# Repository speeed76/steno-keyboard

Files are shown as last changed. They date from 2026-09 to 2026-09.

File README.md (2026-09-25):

# Steno/QWERTY dual-mode keyboard

A 42-key keyboard (3×12 + 6 thumb keys) that works as a normal QWERTY keyboard
or as a steno machine that translates chords **on the keyboard itself**, so the
computer needs no Plover install.

## Status

| Part | State |
|---|---|
| PCB (`hardware/`) | placed and netlisted, **not routed yet**. Ergogen generates `hardware/ergogen/output/pcbs/steno_qwerty.kicad_pcb`; traces still need routing in KiCad |
| Firmware (`firmware/`) | **draft, never run on hardware.** The steno engine works on a desktop against Plover's real dictionary; USB and matrix code is untested |
| Dictionary compiler (`tools/build_dictionary.py`) | works: Plover `main.json` → 2.8 MB binary file |

## Hardware constraint found so far

Plover's default dictionary is still ~2.6 MB after compiling to a compact
binary format. A standard Raspberry Pi Pico (2 MB flash, ~1 MB free under
CircuitPython) **cannot hold it**. The PCB uses the standard Pico footprint,
but fit a module with ≥4 MB of flash (Raspberry Pi Pico 2) or, better, 16 MB.

## PCB

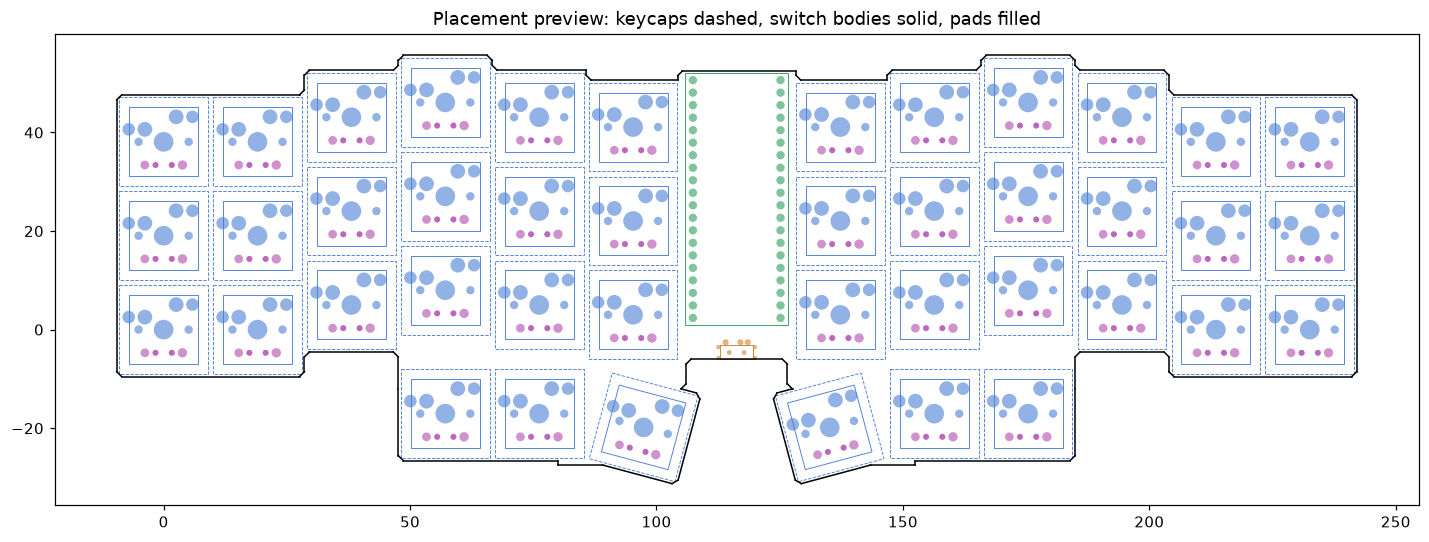
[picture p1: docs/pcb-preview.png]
placement preview


- 42 MX switches with Kailh hotswap sockets, one diode per key (SOD-123 or THT 1N4148)
- Raspberry Pi Pico-footprint module, soldered through-hole, USB at the top edge
- MSK-12C02 slide switch at the bottom notch: GP22 to GND, closed = steno
- Matrix: rows GP6–GP9, columns GP0–GP5 (left) and GP21–GP16 (right), matching `firmware/stenokb/config.py`
- Board is ~250 × 88 mm: over JLCPCB's 100 × 100 mm budget tier, so expect ~$25–40 for 5 bare boards

Regenerate and check it:

```sh
npx ergogen@4.2.1 hardware/ergogen -o hardware/ergogen/output --clean
python3 hardware/tools/check_pcb.py hardware/ergogen/output/pcbs/steno_qwerty.kicad_pcb --png docs/pcb-preview.png
```

`check_pcb.py` is a quick placement check (single board outline, pads inside
it, no colliding switches/keycaps/Pico/switch), not a substitute for KiCad's DRC.

### Remaining steps before ordering

1. Open the `.kicad_pcb` in KiCad 8/9 and route it: by hand, with Freerouting
   (export Specctra DSN, route, import SES), or with Quilter.
2. Add GND fill zones on both layers and run DRC.
3. Plot Gerbers and drill files and upload them to JLCPCB/PCBWay.

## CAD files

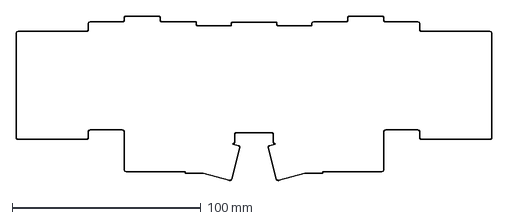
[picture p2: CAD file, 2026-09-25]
hardware/ergogen/output/outlines/board.dxf
251.6 x 87.0 mm

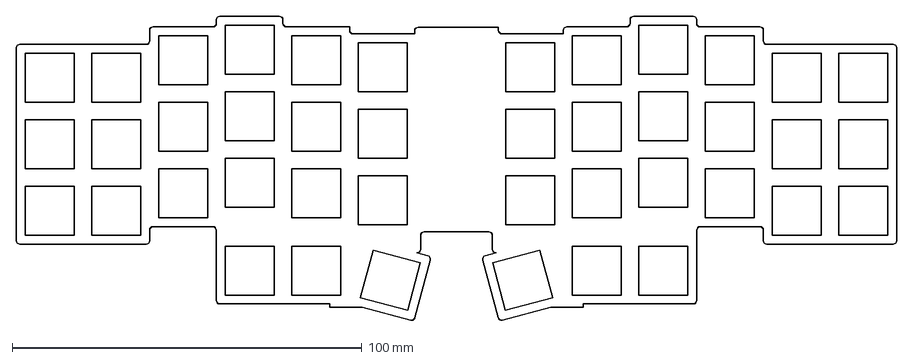
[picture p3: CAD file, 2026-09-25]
hardware/ergogen/output/outlines/preview.dxf
251.6 x 87.0 mm

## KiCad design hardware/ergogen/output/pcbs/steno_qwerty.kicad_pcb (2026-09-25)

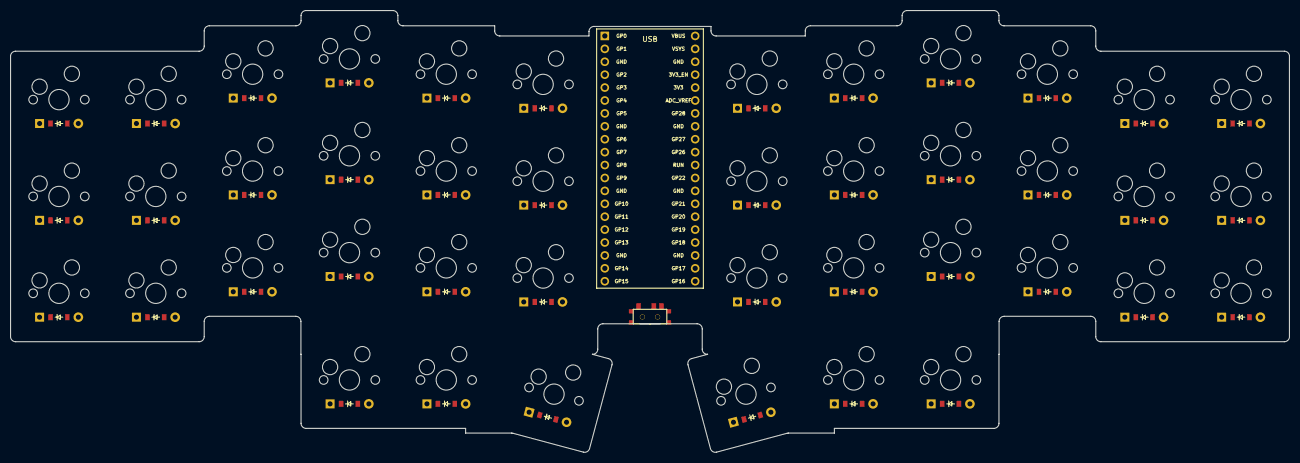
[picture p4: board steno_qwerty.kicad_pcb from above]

Board: 2 copper layers, 251.6 x 86.9 mm, 86 parts (0 on the bottom side), 60 nets, no tracks yet.

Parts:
D1, D2, D3, D4, D5, D6, D7, D8, D9, D10, D11, D12, D13, D14, D15, D16, D17, D18, D19, D20, D21, D22, D23, D24, D25, D26, D27, D28, D29, D30, D31, D32, D33, D34, D35, D36, D37, D38, D39, D40, D41, D42: ComboDiode
MCU1: RPi Pico; RPi_Pico
S1, S2, S3, S4, S5, S6, S7, S8, S9, S10, S11, S12, S13, S14, S15, S16, S17, S18, S19, S20, S21, S22, S23, S24, S25, S26, S27, S28, S29, S30, S31, S32, S33, S34, S35, S36, S37, S38, S39, S40, S41, S42: MX
T1: SPDT_C128955

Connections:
GND: MCU1.3, MCU1.8, MCU1.13, MCU1.18, MCU1.23, MCU1.28, MCU1.33, MCU1.38, T1.2
GP0: MCU1.1, S1.1, S2.1, S3.1
GP1: MCU1.2, S4.1, S5.1, S6.1
GP2: MCU1.4, S7.1, S8.1, S9.1
GP3: MCU1.5, S10.1, S11.1, S12.1, S19.1
GP4: MCU1.6, S13.1, S14.1, S15.1, S20.1
GP5: MCU1.7, S16.1, S17.1, S18.1, S21.1
GP6: D3.1, D6.1, D9.1, D12.1, D15.1, D18.1, D24.1, D27.1, D30.1, D33.1, D36.1, D39.1, MCU1.9
GP7: D2.1, D5.1, D8.1, D11.1, D14.1, D17.1, D23.1, D26.1, D29.1, D32.1, D35.1, D38.1, MCU1.10
GP8: D1.1, D4.1, D7.1, D10.1, D13.1, D16.1, D22.1, D25.1, D28.1, D31.1, D34.1, D37.1, MCU1.11
GP9: D19.1, D20.1, D21.1, D40.1, D41.1, D42.1, MCU1.12
GP16: MCU1.21, S22.1, S23.1, S24.1
GP17: MCU1.22, S25.1, S26.1, S27.1
GP18: MCU1.24, S28.1, S29.1, S30.1
GP19: MCU1.25, S31.1, S32.1, S33.1, S40.1
GP20: MCU1.26, S34.1, S35.1, S36.1, S41.1
GP21: MCU1.27, S37.1, S38.1, S39.1, S42.1
GP22: MCU1.29, T1.1
far_cluster: D21.2, S21.2
home_cluster: D20.2, S20.2
index_bottom: D13.2, S13.2
index_home: D14.2, S14.2
index_top: D15.2, S15.2
inner_bottom: D16.2, S16.2
inner_home: D17.2, S17.2
inner_top: D18.2, S18.2
middle_bottom: D10.2, S10.2
middle_home: D11.2, S11.2
middle_top: D12.2, S12.2
mirror_far_cluster: D42.2, S42.2
mirror_home_cluster: D41.2, S41.2
mirror_index_bottom: D34.2, S34.2
mirror_index_home: D35.2, S35.2
mirror_index_top: D36.2, S36.2
mirror_inner_bottom: D37.2, S37.2
mirror_inner_home: D38.2, S38.2
mirror_inner_top: D39.2, S39.2
mirror_middle_bottom: D31.2, S31.2
mirror_middle_home: D32.2, S32.2
mirror_middle_top: D33.2, S33.2
mirror_near_cluster: D40.2, S40.2
mirror_outer_bottom: D22.2, S22.2
mirror_outer_home: D23.2, S23.2
mirror_outer_top: D24.2, S24.2
mirror_pinky_bottom: D25.2, S25.2
mirror_pinky_home: D26.2, S26.2
mirror_pinky_top: D27.2, S27.2
mirror_ring_bottom: D28.2, S28.2
mirror_ring_home: D29.2, S29.2
mirror_ring_top: D30.2, S30.2
near_cluster: D19.2, S19.2
outer_bottom: D1.2, S1.2
outer_home: D2.2, S2.2
outer_top: D3.2, S3.2
pinky_bottom: D4.2, S4.2
pinky_home: D5.2, S5.2
pinky_top: D6.2, S6.2
ring_bottom: D7.2, S7.2
ring_home: D8.2, S8.2
ring_top: D9.2, S9.2

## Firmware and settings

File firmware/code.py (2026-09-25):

"""Dual-mode steno/QWERTY keyboard firmware (CircuitPython, RP2040/RP2350).

QWERTY mode: a layered 42-key keyboard.
Steno mode: chords are translated on the keyboard itself using the dictionaries
in /dictionaries and typed out as ordinary keystrokes, so the computer needs no
steno software.
"""

import time

import board
import digitalio
import keypad
import usb_hid
from adafruit_hid.keyboard import Keyboard
from adafruit_hid.keyboard_layout_us import KeyboardLayoutUS

from stenokb import config, layout
from stenokb.chord import ChordCollector
from stenokb.device import HidKeys, StenoOutput, load_dictionaries
from stenokb.qwerty import Qwerty
from stenokb.translator import Translator


def pin(name):
    return getattr(board, name)


keyboard = Keyboard(usb_hid.devices)
steno_out = StenoOutput(keyboard, KeyboardLayoutUS(keyboard))

matrix = keypad.KeyMatrix(
    row_pins=[pin(p) for p in config.ROW_PINS],
    column_pins=[pin(p) for p in config.COL_PINS],
    columns_to_anodes=config.COLUMNS_TO_ANODES,
    interval=config.DEBOUNCE_SECONDS,
)

mode_switch = None
if config.MODE_SWITCH_PIN:
    mode_switch = digitalio.DigitalInOut(pin(config.MODE_SWITCH_PIN))
    mode_switch.switch_to_input(pull=digitalio.Pull.UP)

led = None
if config.LED_PIN and hasattr(board, config.LED_PIN):
    led = digitalio.DigitalInOut(pin(config.LED_PIN))
    led.switch_to_output()

translator = Translator(load_dictionaries(config.DICTIONARIES), steno_out)
chords = ChordCollector(layout.STENO)
state = {"mode": None}


def set_mode(mode):
    if mode == state["mode"]:
        return
    qwerty.release_all()
    keyboard.release_all()
    chords.reset()
    translator.reset()
    state["mode"] = mode
    if led:
        led.value = mode == "steno"
    print("mode:", mode)


qwerty = Qwerty(layout.LAYERS, HidKeys(keyboard), on_steno=lambda: set_mode("steno"))


def switch_mode():
    return "steno" if not mode_switch.value else "qwerty"


last_switch = switch_mode() if mode_switch else None
set_mode(last_switch or config.DEFAULT_MODE)

event = keypad.Event()
while True:
    if mode_switch:
        position = switch_mode()
        if position != last_switch:
            last_switch = position
            set_mode(position)

    if not matrix.events.get_into(event):
        time.sleep(0.001)
        continue

    key = event.key_number
    if state["mode"] == "qwerty":
        if event.pressed:
            qwerty.press(key)
        else:
            qwerty.release(key)
        continue

    if event.pressed:
        chords.press(key)
        continue
    chord = chords.release(key)
    if not chord:
        continue
    if chords.is_mode_chord(chord):
        set_mode("qwerty")
        continue
    stroke = chords.to_stroke(chord)
    if stroke:
        translator.stroke(stroke)

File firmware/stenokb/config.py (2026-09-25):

"""Hardware configuration. Must match the PCB (hardware/ergogen/config.yaml)."""

# Matrix wiring: diodes point from column (anode) to row (cathode).
ROW_PINS = ("GP6", "GP7", "GP8", "GP9")
COL_PINS = (
    "GP0", "GP1", "GP2", "GP3", "GP4", "GP5",          # left half, outer -> inner
    "GP21", "GP20", "GP19", "GP18", "GP17", "GP16",    # right half, inner -> outer
)
COLUMNS_TO_ANODES = True

# SPDT slide switch: common pin to GPIO, one throw to GND. Set to None if not fitted.
# Switch closed (pin reads low) = steno mode.
MODE_SWITCH_PIN = "GP22"

# Mode indicator: on-board LED lit in steno mode (None to disable).
LED_PIN = "LED"

DEBOUNCE_SECONDS = 0.005

# Dictionaries, searched in order: the first one with a translation wins.
# *.json files are loaded into RAM (keep them small); *.stnd files are compiled
# with tools/build_dictionary.py and read from flash.
DICTIONARIES = (
    "/dictionaries/user.json",
    "/dictionaries/main.stnd",
)

# Mode at power-up when no mode switch is fitted: "steno" or "qwerty".
DEFAULT_MODE = "qwerty"

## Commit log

2026-09-25 Add draft on-device steno firmware and dictionary compiler
    Firmware is untested on hardware; the steno translator runs on a desktop
    against Plover's main dictionary. PCB work follows.
    Claude-Session: https://claude.ai/code/session_01E1cnTPA3U2YqDRzM8WDUU7
2026-09-25 Add Ergogen PCB layout with Pico footprint and placement checker
    42-key 3x12+6 columnar board, Pico-footprint MCU between the halves, mode
    slide switch on GP22. Generated KiCad file is placed and netlisted but not
    routed yet.
    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
    [board.dxf, preview.dxf, steno_qwerty.kicad_pcb]
